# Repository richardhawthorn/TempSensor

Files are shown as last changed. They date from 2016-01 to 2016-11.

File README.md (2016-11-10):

### Description

PCB and Arduino code for a basic temperature sensor

### Features

- 4 character 7-segment LED display
- ATMEGA328P with Arduino boot-loader
- 5V operation @ 16Mhz
- DS18B20 temperature sensor
- 1x button to select unit
- Mini USB power connector
- FTDI programming port
- ICSP port

### License

This work is licensed under a Creative Commons Attribution-ShareAlike 4.0 International License.

<br />
Designed by <a xmlns:cc="http://creativecommons.org/ns#" href="http://www.richardhawthorn.com" property="cc:attributionName" rel="cc:attributionURL" target="_blank">Richard Hawthorn</a><br />
<a rel="license" href="http://creativecommons.org/licenses/by-sa/4.0/" target="_blank">View License</a>

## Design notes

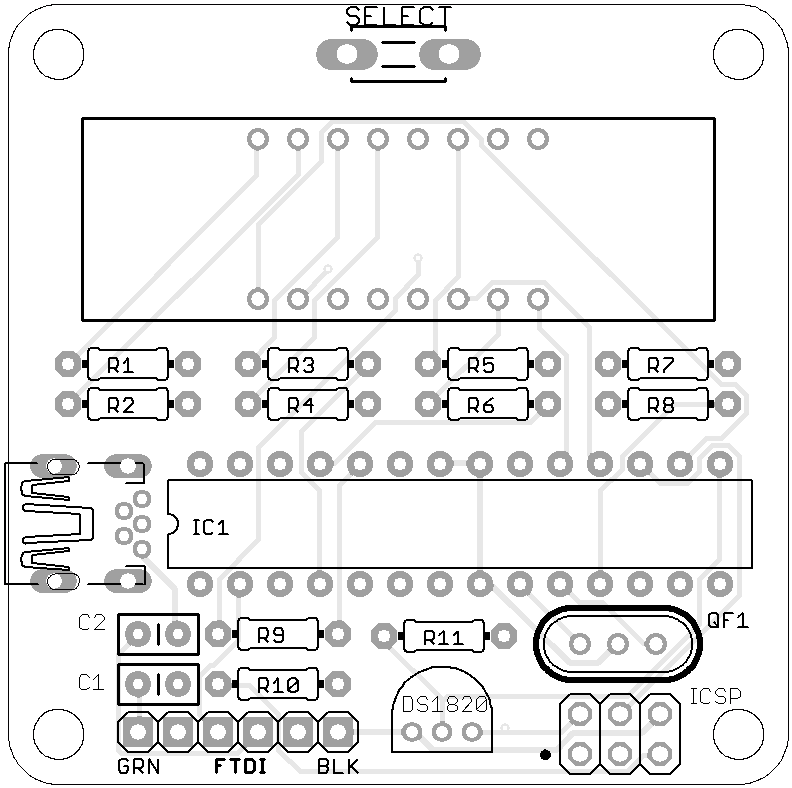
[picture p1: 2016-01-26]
images/pcb_front.png

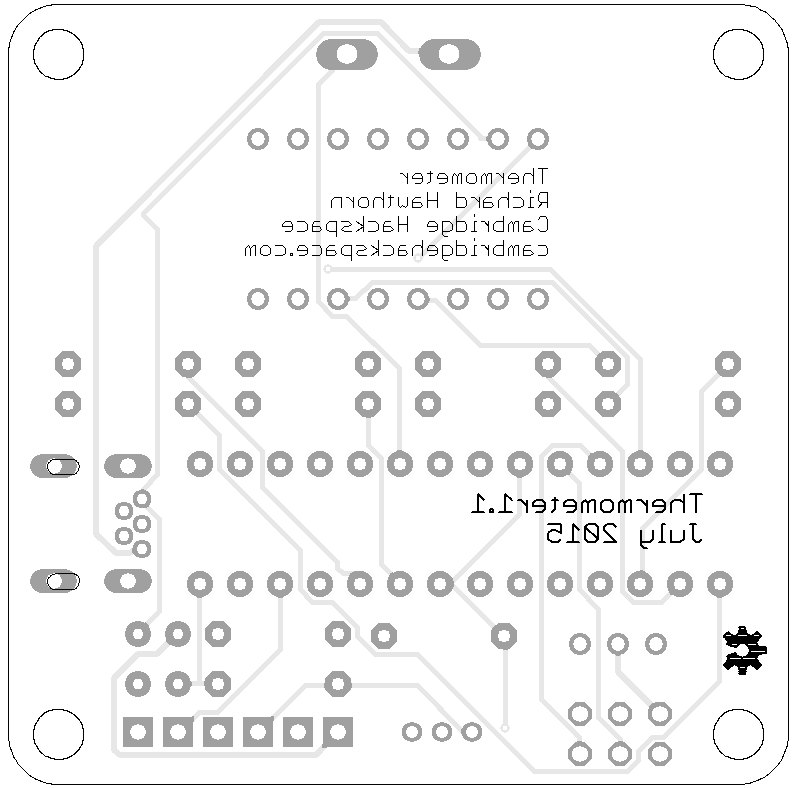
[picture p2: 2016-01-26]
images/pcb_back.png

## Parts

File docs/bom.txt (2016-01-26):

### Parts list

Qty  Value       Description          Parts 
           
2    0.1         Capacitor            C1, C2                                        
1    10K         Resistor             R10, R11                                              
1    7SEG        7 Segment LED        LED1           
9    82r         Resistor             R1, R2, R3, R4, R5, R6, R7, R8, R9     
1    8M10AHC49T  Crystal              QF1          
1    ATMEGA328P  Microcontroller      IC1                                        
1    DS1820      Temp Sensor          U$1                             
1    FTDI        6 Pin Header         CN4                                                                
1    SELECT      Button               BTN1                                             
1    USB         USB connector 	      X1    

### Additional Hardware

1 x IC Socket  
1 x PCB  
1 x Front Plate  
4 x Pillars  
8 x Screws

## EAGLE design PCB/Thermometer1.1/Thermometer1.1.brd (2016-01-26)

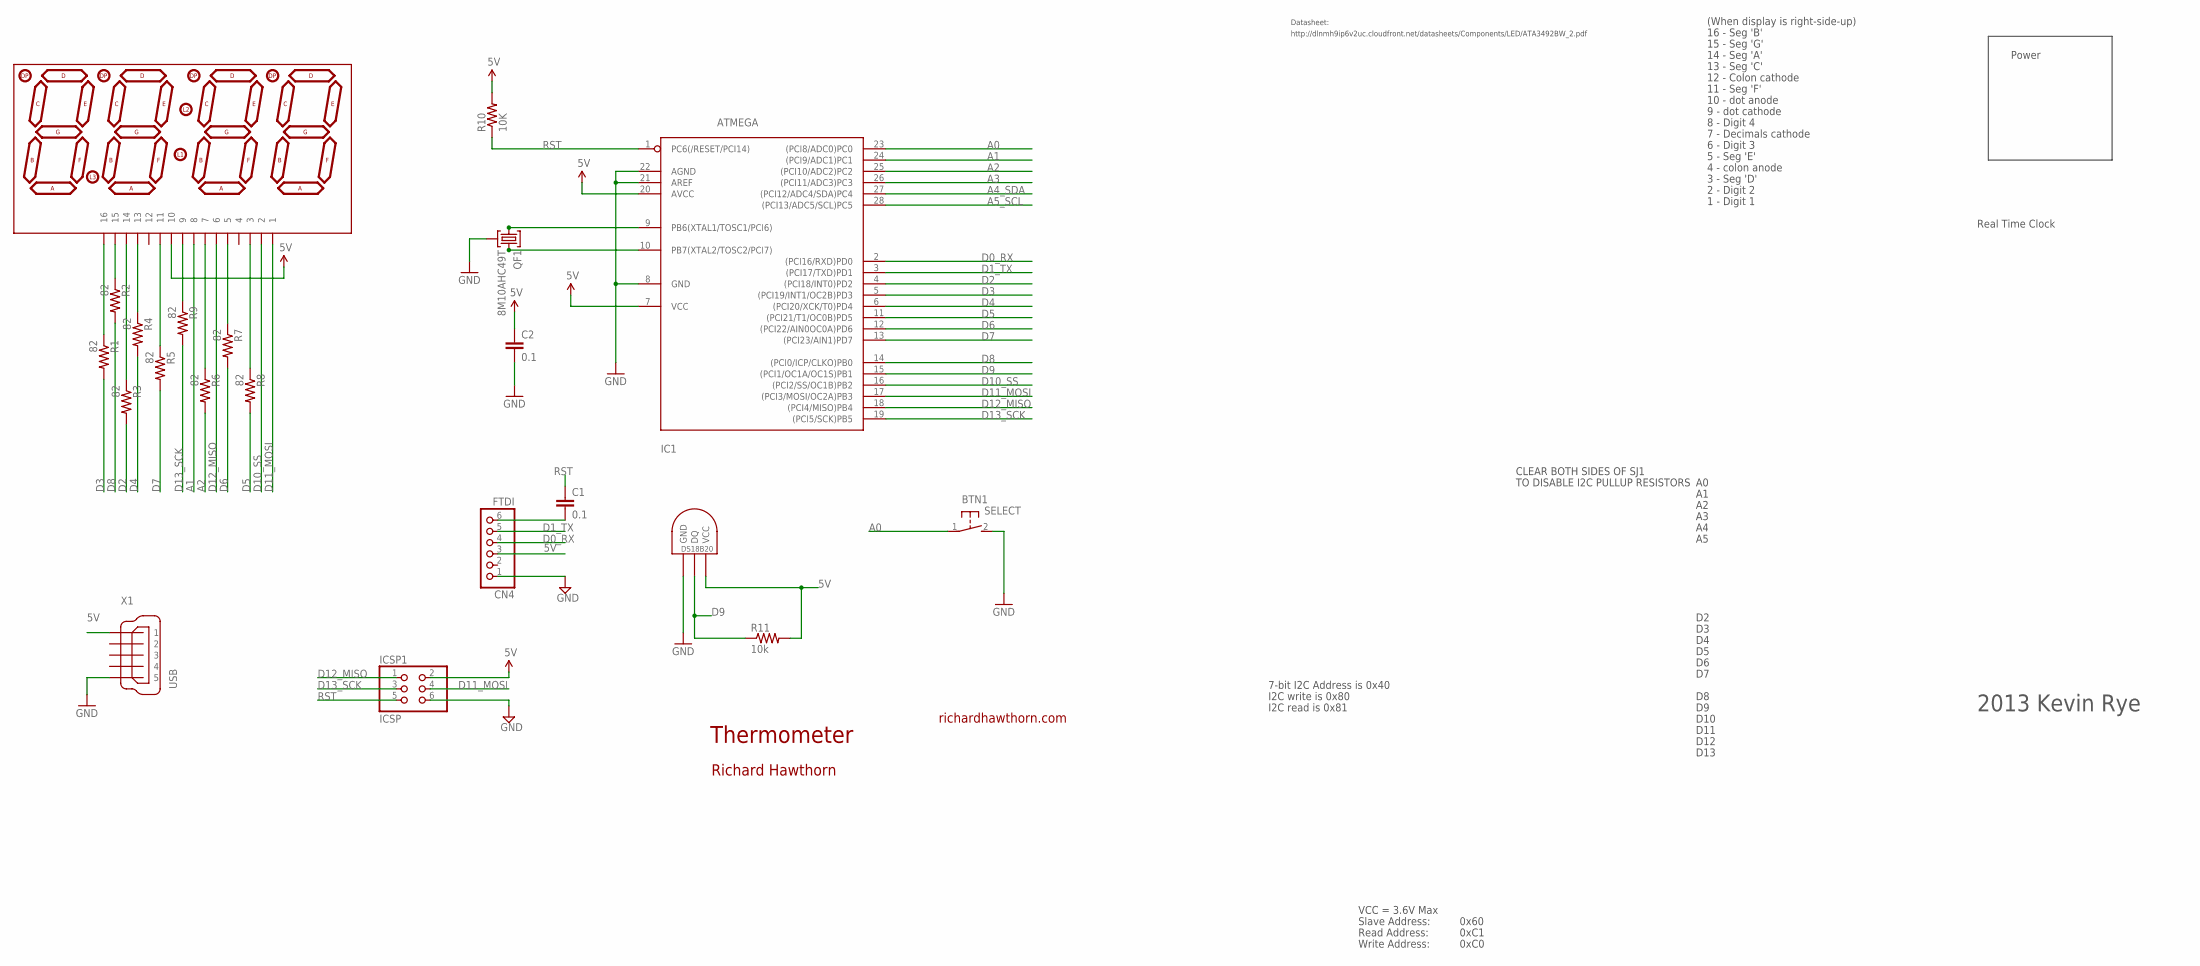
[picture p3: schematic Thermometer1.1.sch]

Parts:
BTN1: SELECT; DTS-3
C1, C2: 0.1; CAP-PTH-SMALL2
CN4: FTDI; 1X06
IC1: ATMEGA; DIL28-3-ROUND
ICSP1: ICSP; 2X03
LED1: 7SEG-4DIGIT; SPARKFUN_7-SEGMENT-4DIGIT
QF1: 8M10AHC49T; HC49U
R1, R2, R3, R4, R5, R6, R7, R8, R9: 82; 0204/7
R10: 10K; 0204/7
R11: 10k; 0204/7
U$1: DS1820TO92; DS1820
X1: USB; 32005-601

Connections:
5V: C2.1, CN4.3, IC1.7 (VCC), IC1.20 (AVCC), ICSP1.2, LED1.10, R10.2, R11.2, U$1.VDD (VCC), X1.1
A0: BTN1.1, IC1.23 ((PCI8/ADC0)PC0)
A1: IC1.24 ((PCI9/ADC1)PC1), R9.2
A2: IC1.25 ((PCI10/ADC2)PC2), R6.2
A3: IC1.26 ((PCI11/ADC3)PC3)
A4_SDA: IC1.27 ((PCI12/ADC4/SDA)PC4)
A5_SCL: IC1.28 ((PCI13/ADC5/SCL)PC5)
D0_RX: CN4.4, IC1.2 ((PCI16/RXD)PD0)
D1_TX: CN4.5, IC1.3 ((PCI17/TXD)PD1)
D2: IC1.4 ((PCI18/INT0)PD2), R3.2
D3: IC1.5 ((PCI19/INT1/OC2B)PD3), R1.2
D4: IC1.6 ((PCI20/XCK/T0)PD4), R4.2
D5: IC1.11 ((PCI21/T1/OC0B)PD5), R8.2
D6: IC1.12 ((PCI22/AIN0OC0A)PD6), R7.2
D7: IC1.13 ((PCI23/AIN1)PD7), R5.2
D8: IC1.14 ((PCI0/ICP/CLKO)PB0), R2.2
D9: IC1.15 ((PCI1/OC1A/OC1S)PB1), R11.1, U$1.DQ
D10_SS: IC1.16 ((PCI2/SS/OC1B)PB2), LED1.1
D11_MOSI: IC1.17 ((PCI3/MOSI/OC2A)PB3), ICSP1.4, LED1.2
D12_MISO: IC1.18 ((PCI4/MISO)PB4), ICSP1.1, LED1.6
D13_SCK: IC1.19 ((PCI5/SCK)PB5), ICSP1.3, LED1.8
GND: BTN1.2, C2.2, CN4.1, IC1.8 (GND), IC1.21 (AREF), IC1.22 (AGND), ICSP1.6, QF1.2, U$1.GND, X1.5
unnamed: LED1.16, R1.1
unnamed: LED1.15, R2.1
unnamed: LED1.9, R9.1
unnamed: LED1.7, R6.1
unnamed: IC1.9 (PB6(XTAL1/TOSC1/PCI6)), QF1.1
unnamed: C1.2, CN4.6
unnamed: LED1.13, R4.1
unnamed: LED1.14, R3.1
unnamed: LED1.11, R5.1
unnamed: IC1.10 (PB7(XTAL2/TOSC2/PCI7)), QF1.3
unnamed: LED1.5, R7.1
unnamed: LED1.3, R8.1
RST: C1.1, IC1.1 (PC6(/RESET/PCI14)), ICSP1.5, R10.1

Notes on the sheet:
Thermometer
richardhawthorn.com
Richard Hawthorn
CLEAR BOTH SIDES OF SJ1
TO DISABLE I2C PULLUP RESISTORS
7-bit I2C Address is 0x40
I2C write is 0x80
I2C read is 0x81
VCC = 3.6V Max
Read Address:
Write Address:
Slave Address:
0x60
0xC1
0xC0
14 - Seg 'A'
13 - Seg 'C'
12 - Colon cathode
11 - Seg 'F'
10 - dot anode
9 - dot cathode
8 - Digit 4
7 - Decimals cathode
6 - Digit 3
5 - Seg 'E'
4 - colon anode
3 - Seg 'D'
2 - Digit 2
Real Time Clock
1 - Digit 1
15 - Seg 'G'
16 - Seg 'B'
D10
D11
D12
D13
http://dlnmh9ip6v2uc.cloudfront.net/datasheets/Components/LED/ATA3492BW_2.pdf
Datasheet:
Power
(When display is right-side-up)

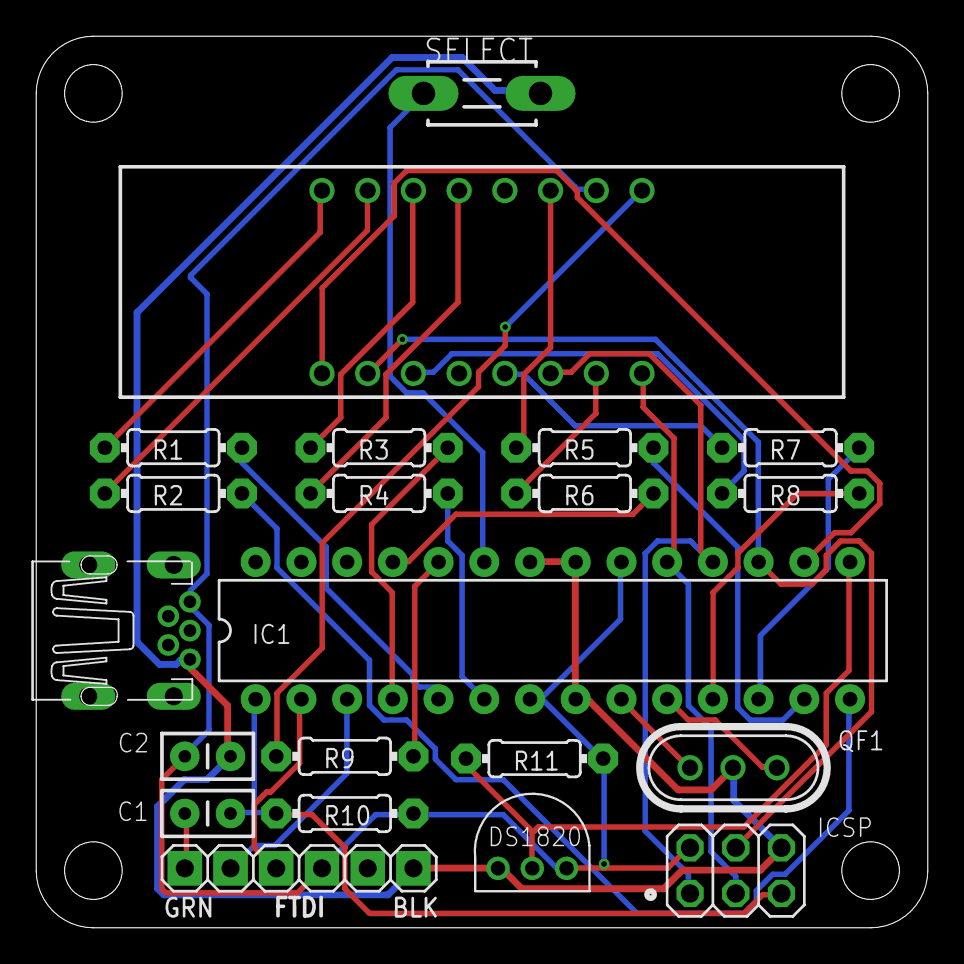
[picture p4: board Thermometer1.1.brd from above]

Board: 2 copper layers, 49.5 x 49.5 mm, 22 parts (1 on the bottom side), 32 nets.

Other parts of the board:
U$3: OSHW-LOGO-S

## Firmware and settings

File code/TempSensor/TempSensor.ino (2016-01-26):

//   Temp Sensor
//   Richard Hawthorn
//   Cambridge Hackspace
//   2015-11-21
//
//   7 segment led pixels
//
//    _____         __A__
//   |     |       F     B
//   |_____|  -->  |--G--|
//   |     |       E     C
//   |_____|       |__D__|
//
//   Characters
//    _____     _____     _____     _____ 
//   |     |   |     | . |     | o |     |
//   |_____|   |_____|   |_____|   |_____|
//   |     |   |     | . |     |   |     |
//   |_____| o |_____| o |_____| o |_____| o
//      1         2         3         4
//

//how long to pause between drawing each character
int displayPause = 1;

//define Pins
int segmentD = 5;
int segmentE = 6;
int segmentF = 7;
int segmentA = 2;
int segmentB = 3;
int segmentC = 4;
int segmentG = 8;
int digitOne = 10;
int digitTwo = 11;
int digitThree = 12;
int digitFour = 13;
int selectButton = A0;
int degs = A1;
int decimal = A2;

//current temperature
int temp = 0;

//temperature units
char unit = 'c';

//counter for re-checking the temperature
long count = 0;

//how frequently should we re-check the temperature, in minutes
int minutes = 1;

//setup the one wire sensor
#include <OneWire.h>
#include <DallasTemperature.h>
#define ONE_WIRE_BUS 9
OneWire oneWire(ONE_WIRE_BUS);
DallasTemperature sensors(&oneWire);

//setup
void setup() {

  //pin modes
  pinMode(segmentA, OUTPUT);
  pinMode(segmentB, OUTPUT);
  pinMode(segmentC, OUTPUT);
  pinMode(segmentD, OUTPUT);
  pinMode(segmentE, OUTPUT);
  pinMode(segmentF, OUTPUT);
  pinMode(segmentG, OUTPUT);
  pinMode(digitOne, OUTPUT);
  pinMode(digitTwo, OUTPUT);
  pinMode(digitThree, OUTPUT);
  pinMode(digitFour, OUTPUT);
  pinMode(decimal, OUTPUT);
  pinMode(degs, OUTPUT);

  //turn off the degrees symbol on boot
  digitalWrite(degs,HIGH);
  
  //buttons (with pullups)
  pinMode(selectButton, INPUT_PULLUP);
  
  //setup serial line for debugging
  Serial.begin(9600);
  Serial.println("Temperature Sensor Starting...");

  //start the temp sensor
  sensors.begin();
  
}


//get the current temperature
void getTemp(){

  if (count == 0){
    
    count = (minutes * 13000);
    resetNumbers();
    sensors.requestTemperatures();

    if (unit == 'c'){
      temp = sensors.getTempCByIndex(0) * 100;  
    } else {
      temp = sensors.getTempFByIndex(0) * 100;  
    }
    
  } else {
    count--;
  }
 
}



//check the buttons
void checkButtons(){
  
  //select button pressed
  if (digitalRead(selectButton) == LOW) {

    if (unit == 'c'){
      unit = 'f';
      count = 0;
    } else {
      unit = 'c';
      count = 0;
    }
  } 

}

//display the temperature
void showNum(int n) {

  //display digit 1
  int n1 = (n%10000)/1000;
  printNumber(n1, 1, false); 
  delay(displayPause);
  resetNumbers();

  //digit 2
  int n2 = (n%1000)/100;
  printNumber(n2, 2, true); 
  delay(displayPause);
  resetNumbers();

  //digit 3
  int n3 = (n%100)/10;
  printNumber(n3, 3, false);
  delay(displayPause);
  resetNumbers();

  //digit 4
  printNumber(unit, 4, false); 
  delay(displayPause);
  resetNumbers();

}

//reset the screen, so everything is off
void resetNumbers(){
  
    digitalWrite(digitOne,LOW);
    digitalWrite(digitTwo,LOW);
    digitalWrite(digitThree,LOW);
    digitalWrite(digitFour,LOW);
    digitalWrite(decimal,HIGH);
    digitalWrite(degs,HIGH);
    digitalWrite(segmentA,HIGH);
    digitalWrite(segmentB,HIGH);
    digitalWrite(segmentC,HIGH);
    digitalWrite(segmentD,HIGH);
    digitalWrite(segmentE,HIGH);
    digitalWrite(segmentF,HIGH);
    digitalWrite(segmentG,HIGH);  
  
}

//output a specific number in a specific position
//n = number, d = position
void printNumber(int n, int d, int dec) {
  
  if ((d > 4) || (d < 1)){
    return;  
  }

  //so we only light up the degrees led for the same time as the other leds
  if (d == 1){
    digitalWrite(degs,LOW); 
  }

  if (dec){
    digitalWrite(decimal,LOW); 
  }
  
  //d is the display to illuminate
  if(d==1)  {
    digitalWrite(digitOne,HIGH);
    digitalWrite(digitTwo,LOW);
    digitalWrite(digitThree,LOW);
    digitalWrite(digitFour,LOW);
  } 

  if(d==2) {
    digitalWrite(digitOne,LOW);
    digitalWrite(digitTwo,HIGH);
    digitalWrite(digitThree, LOW);
    digitalWrite(digitFour,LOW);
  }

  if(d==3) {
    digitalWrite(digitOne,LOW);
    digitalWrite(digitTwo,LOW);
    digitalWrite(digitThree,HIGH);
    digitalWrite(digitFour,LOW);
  }

  if(d==4) {
    digitalWrite(digitOne,LOW);
    digitalWrite(digitTwo,LOW);
    digitalWrite(digitThree,LOW);
    digitalWrite(digitFour,HIGH);
  }
 
  //n is for the number/character to be displayed
  switch(n) {
  case 0:
    digitalWrite(segmentA,LOW);
    digitalWrite(segmentB,LOW);
    digitalWrite(segmentC,LOW);
    digitalWrite(segmentD,LOW);
    digitalWrite(segmentE,LOW);
    digitalWrite(segmentF,LOW);
    digitalWrite(segmentG,HIGH);
    break;
    

  case 1:
    digitalWrite(segmentA,HIGH);
    digitalWrite(segmentB,LOW);
    digitalWrite(segmentC,LOW);
    digitalWrite(segmentD,HIGH);
    digitalWrite(segmentE,HIGH);
    digitalWrite(segmentF,HIGH);
    digitalWrite(segmentG,HIGH);
    break;

  case 2:
    digitalWrite(segmentA,LOW);
    digitalWrite(segmentB,LOW);
    digitalWrite(segmentC,HIGH);
    digitalWrite(segmentD,LOW);
    digitalWrite(segmentE,LOW);
    digitalWrite(segmentF,HIGH);
    digitalWrite(segmentG,LOW);
    break;

  case 3:
    digitalWrite(segmentA,LOW);
    digitalWrite(segmentB,LOW);
    digitalWrite(segmentC,LOW);
    digitalWrite(segmentD,LOW);
    digitalWrite(segmentE,HIGH);
    digitalWrite(segmentF,HIGH);
    digitalWrite(segmentG,LOW);
    break;

  case 4:
    digitalWrite(segmentA,HIGH);
    digitalWrite(segmentB,LOW);
    digitalWrite(segmentC,LOW);
    digitalWrite(segmentD,HIGH);
    digitalWrite(segmentE,HIGH);
    digitalWrite(segmentF,LOW);
    digitalWrite(segmentG,LOW);
    break;

  case 5:
    digitalWrite(segmentA,LOW);
    digitalWrite(segmentB,HIGH);
    digitalWrite(segmentC,LOW);
    digitalWrite(segmentD,LOW);
    digitalWrite(segmentE,HIGH);
    digitalWrite(segmentF,LOW);
    digitalWrite(segmentG,LOW);
    break;

  case 6:
    digitalWrite(segmentA,LOW);
    digitalWrite(segmentB,HIGH);
    digitalWrite(segmentC,LOW);
    digitalWrite(segmentD,LOW);
    digitalWrite(segmentE,LOW);
    digitalWrite(segmentF,LOW);
    digitalWrite(segmentG,LOW);
    break;

  case 7:
    digitalWrite(segmentA,LOW);
    digitalWrite(segmentB,LOW);
    digitalWrite(segmentC,LOW);
    digitalWrite(segmentD,HIGH);
    digitalWrite(segmentE,HIGH);
    digitalWrite(segmentF,HIGH);
    digitalWrite(segmentG,HIGH);
    break;

  case 8:
    digitalWrite(segmentA,LOW);
    digitalWrite(segmentB,LOW);
    digitalWrite(segmentC,LOW);
    digitalWrite(segmentD,LOW);
    digitalWrite(segmentE,LOW);
    digitalWrite(segmentF,LOW);
    digitalWrite(segmentG,LOW);
    break;

  case 9:
    digitalWrite(segmentA,LOW);
    digitalWrite(segmentB,LOW);
    digitalWrite(segmentC,LOW);
    digitalWrite(segmentD,LOW);
    digitalWrite(segmentE,HIGH);
    digitalWrite(segmentF,LOW);
    digitalWrite(segmentG,LOW);
    break;

  case 'c':
    digitalWrite(segmentA,LOW);
    digitalWrite(segmentB,HIGH);
    digitalWrite(segmentC,HIGH);
    digitalWrite(segmentD,LOW);
    digitalWrite(segmentE,LOW);
    digitalWrite(segmentF,LOW);
    digitalWrite(segmentG,HIGH);
    break;

  case 'f':
    digitalWrite(segmentA,LOW);
    digitalWrite(segmentB,HIGH);
    digitalWrite(segmentC,HIGH);
    digitalWrite(segmentD,HIGH);
    digitalWrite(segmentE,LOW);
    digitalWrite(segmentF,LOW);
    digitalWrite(segmentG,LOW);
    break;
  }
}


//main loop
void loop() {
 
  getTemp();
  showNum(temp);
  checkButtons();
  
}

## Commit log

2016-01-26 adding pcb for v1.1
    [Thermometer1.1.brd, Thermometer1.1.sch]
2016-01-26 adding bom
2016-01-26 adding arduino code

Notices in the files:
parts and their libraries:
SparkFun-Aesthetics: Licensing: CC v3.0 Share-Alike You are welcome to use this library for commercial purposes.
